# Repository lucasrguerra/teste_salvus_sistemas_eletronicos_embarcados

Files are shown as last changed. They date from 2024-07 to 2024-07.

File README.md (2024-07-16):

# Teste Técnico para a vaga de Desenvolvedor de Sistemas Eletrônicos Embarcados na Salvus

## Descrição

Este repositório contém minhas respostas para o teste técnico para a vaga de Desenvolvedor de Sistemas Eletrônicos Embarcados na Salvus.

O arquivo [Teste Técnico](Teste_Técnico-Lucas_Rayan_Guerra_da_Silva.pdf) contém a descrição e as questões do teste técnico, assim como as minhas respostas para as questões 2, 3, 4 e 5.

A pasta [Projeto](Projeto) contém os arquivos do projeto do circuito de fonte de alimentação regulada para um microcontrolador de baixa potência que opera com 3.3V a partir de uma fonte de 12V e/ou uma bateria.

A pasta [Arquivos_de_Fabricação](Arquivos_de_Fabricação) contém os arquivos de fabricação do circuito de fonte de alimentação regulada.

O arquivo [Lista_de_Materiais_(BOM)](Lista_de_Materiais_(BOM).csv) contém a lista de materiais (BOM) do circuito de fonte de alimentação regulada.

O arquivo [Esquemático](Esquemático.pdf) contém o esquemático do circuito de fonte de alimentação regulada.

Por questões de tempo, não foi possível realizar a simulação do circuito de fonte de alimentação regulada, devido a utilização de componentes específicos que não são encontrados um equivalente para simulação com facilidade, não tive disposnibilidade o suficiente para catalogar todos eles. Porém, por utilizar um esquema de ligação muito semelhante ao utilizado nos módulos prontos comercializados com o chip TP4056, acredito que o circuito proposto funcione corretamente, garantindo a alternância entre a fonte de alimentação e bateria, bem como as proteções contra sobrecarga e descarga excessiva da bateria.

## Justificativa do uso dos componentes

### Conectores KF301-2P

Eles foram escolhidos por ser de fácil conexão e desconexão, além de serem baratos e fáceis de encontrar.

### Capacitor C1

Ele foi escolhido para filtrar o ruído da fonte de alimentação e garantir que a tensão de entrada do regulador de tensão seja o mais estável possível.

### LED D1

Esse LED na cor verde foi escolhido para indicar que a fonte de alimentação está conectada e funcionando.

### LED D2

Esse LED na cor vermelha foi escolhido para indicar que a bateria está sendo carregada.

### Regulador LM7805

Ele foi escolhido para regular a tensão de entrada de 12V para 5V, que é a tensão utilizada para carregar a bateria. Vale ressaltar que o regulador LM7805 aceita tensões de 7V até 20V, então o circuito pode ser alimentado com tensões de 7V até 20V.

### Regulador AP2112-3.3

Ele foi escolhido para regular a tensão de 5V vinda da fonte de alimentação, ou a tensão da bateria, para 3.3V, que é a tensão de alimentação do microcontrolador. A característica mais importante para essa aplicação é que ele é um LDO (Low Drop-Out), ou seja, ele pode ser alimentado com tensões muito próximas da tensão de saída, o que é o caso quando a bateria está sendo utilizada.

### TP4056

Ele foi escolhido para controlar a carga da bateria de lítio. Ele é um módulo de carga de bateria de lítio de 1A. Ele é muito utilizado em projetos de carregadores de bateria de lítio, por ser barato e fácil de encontrar.

### DW01A

Ele foi escolhido para proteger a bateria de lítio contra sobrecarga e descarga excessiva. Ele normalmente é utilizado em conjunto com o TP4056.

### MOSFET FS8205A

Ele foi escolhido para alternar entre a fonte de alimentação e a bateria. Ele é um MOSFET de canal duplo, e também costuma ser utilizado em conjunto com o TP4056.

### Extras

Também foram acionados 2 barramentos de 2.54mm com 2 pinos cada para facilitar a conexão da bateria e do MCU via Jumpers.

## Images

A pasta [Imagens](Imagens) contém as imagens do circuito de fonte de alimentação regulada mostradas abaixo.

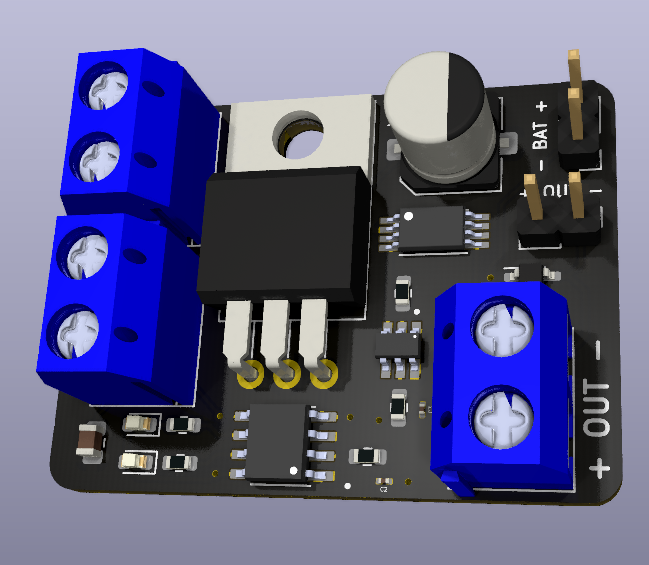
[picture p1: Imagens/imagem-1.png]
Imagem 1


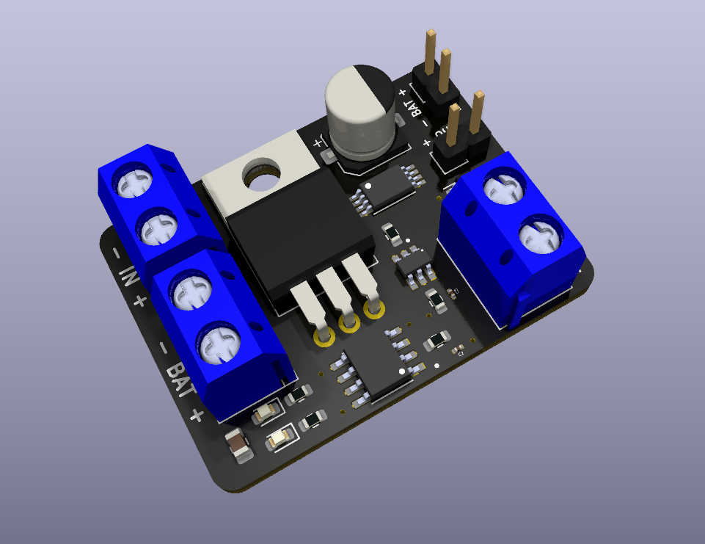
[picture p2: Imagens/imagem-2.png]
Imagem 2


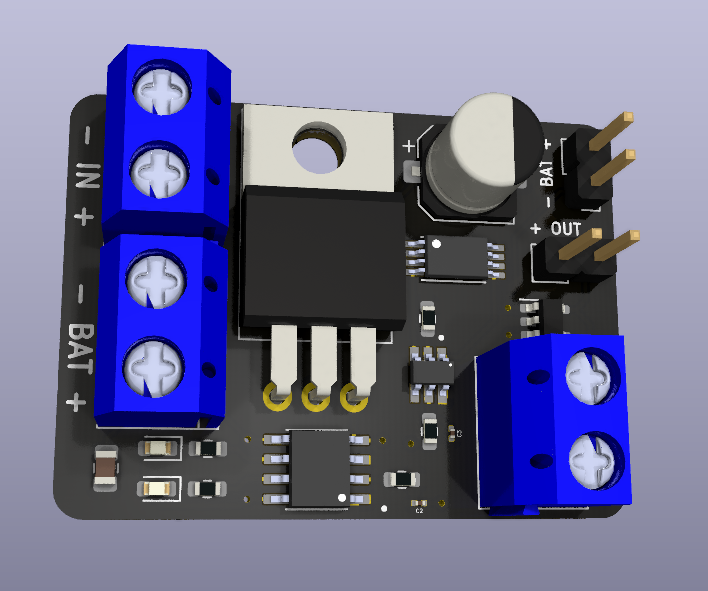
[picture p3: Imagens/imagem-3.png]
Imagem 3


Autor: Lucas Rayan Guerra da Silva

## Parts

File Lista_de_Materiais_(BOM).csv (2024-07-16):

Id | Designador | Footprint | Quantidade | Designação | Referência
1 | D1 | LED_0603_1608Metric | 1 | Green | LED Green 0603
2 | R2,R1,R4 | R_0603_1608Metric | 3 | 1kΩ | Resistor 1kΩ 0.1W 1% 0603
3 | J4,J5 | PinHeader_1x02_P2.54mm_Vertical | 2 | Conn_01x02 | Pin Header 1x02 2.54mm Vertical
4 | C4 | C_0805_2012Metric | 1 | 10uF 10V | Capacitor 10uF 10V 2012
5 | J3,J1,J2 | TerminalBlock_bornier-2_P5.08mm | 3 | KF301-2P | KF301-2P
6 | U1 | TO-220-3_Horizontal_TabDown | 1 | LM7805_TO220 | LM7805_TO220
7 | C3,C2 | C_0201_0603Metric | 2 | 100nF 6.3V | Capacitor 100nF 6.3V 0603
8 | U4 | SOT-23-5 | 1 | AP2112K-3.3 | AP2112K-3.3
9 | U2 | SOP127P600X175-9N | 1 | TP4056 | TP4056 SOP8
10 | R3 | R_0603_1608Metric | 1 | 1.2kΩ | Resistor 1.2kΩ 0.1W 1% 0603
11 | C1 | CP_Elec_6.3x7.7 | 1 | 100uF 35V | Electrolytic capacitor 100uF 35V 6.3x7.7
12 | Q1 | SOP65P640X120-8N | 1 | FS8205A | FS8205A SOP8
13 | D2 | LED_0603_1608Metric | 1 | Red | LED Red 0603
14 | R5 | R_0603_1608Metric | 1 | 100Ω | Resistor 100Ω 0.1W 1% 0603
15 | U3 | SOT95P280X145-6N | 1 | DW01A | DW01A SOT23

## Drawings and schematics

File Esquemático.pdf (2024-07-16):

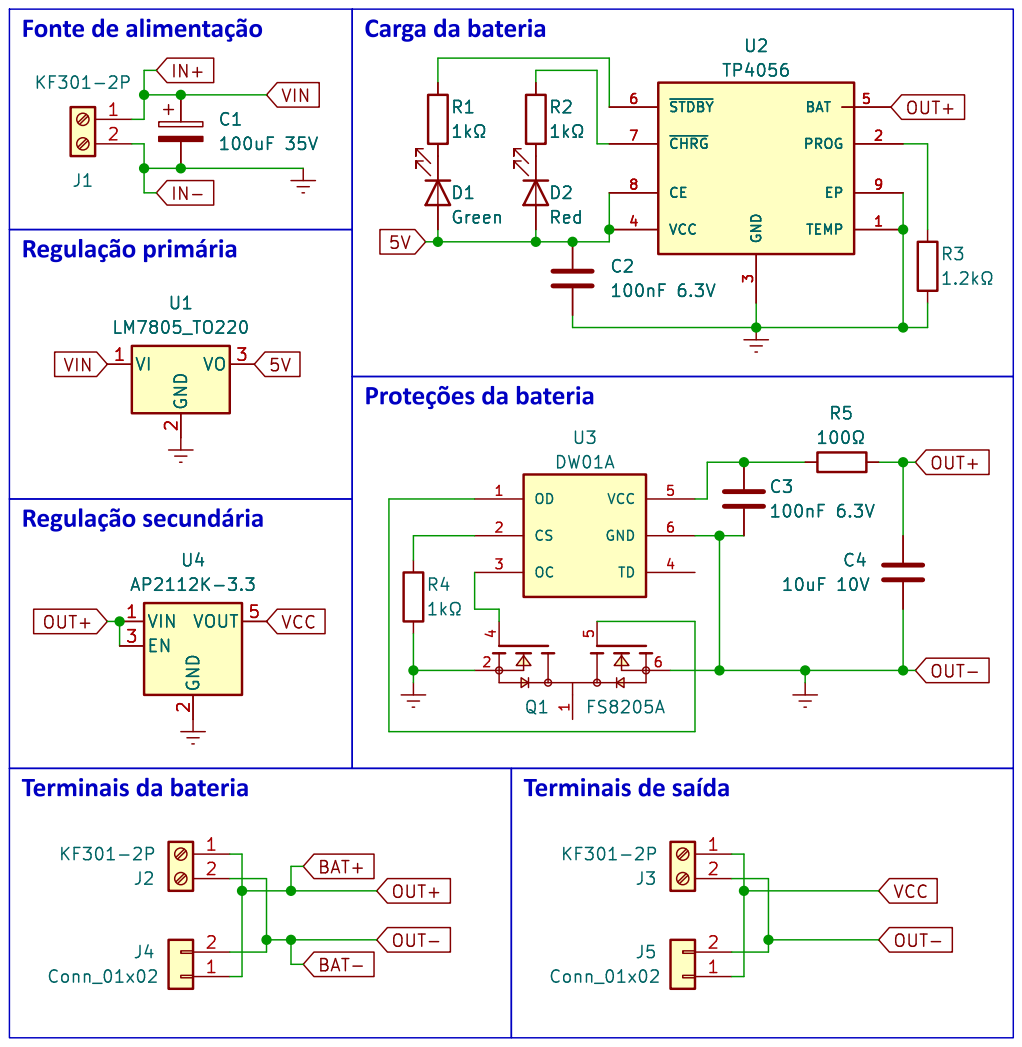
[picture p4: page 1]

3 VCC 4 BAT 5 ~{STDBY} 6 ~{CHRG} 7 CE 8 EP 9 U2 TP4056 R3

3 VCC 4 BAT 5 ~{STDBY} 6 ~{CHRG} 7 CE 8 EP 9 D2 Red R2
10uF 10V D2 Red R2

Id: 1/1 Title: þÿEsquemático do Teste þÿPrático

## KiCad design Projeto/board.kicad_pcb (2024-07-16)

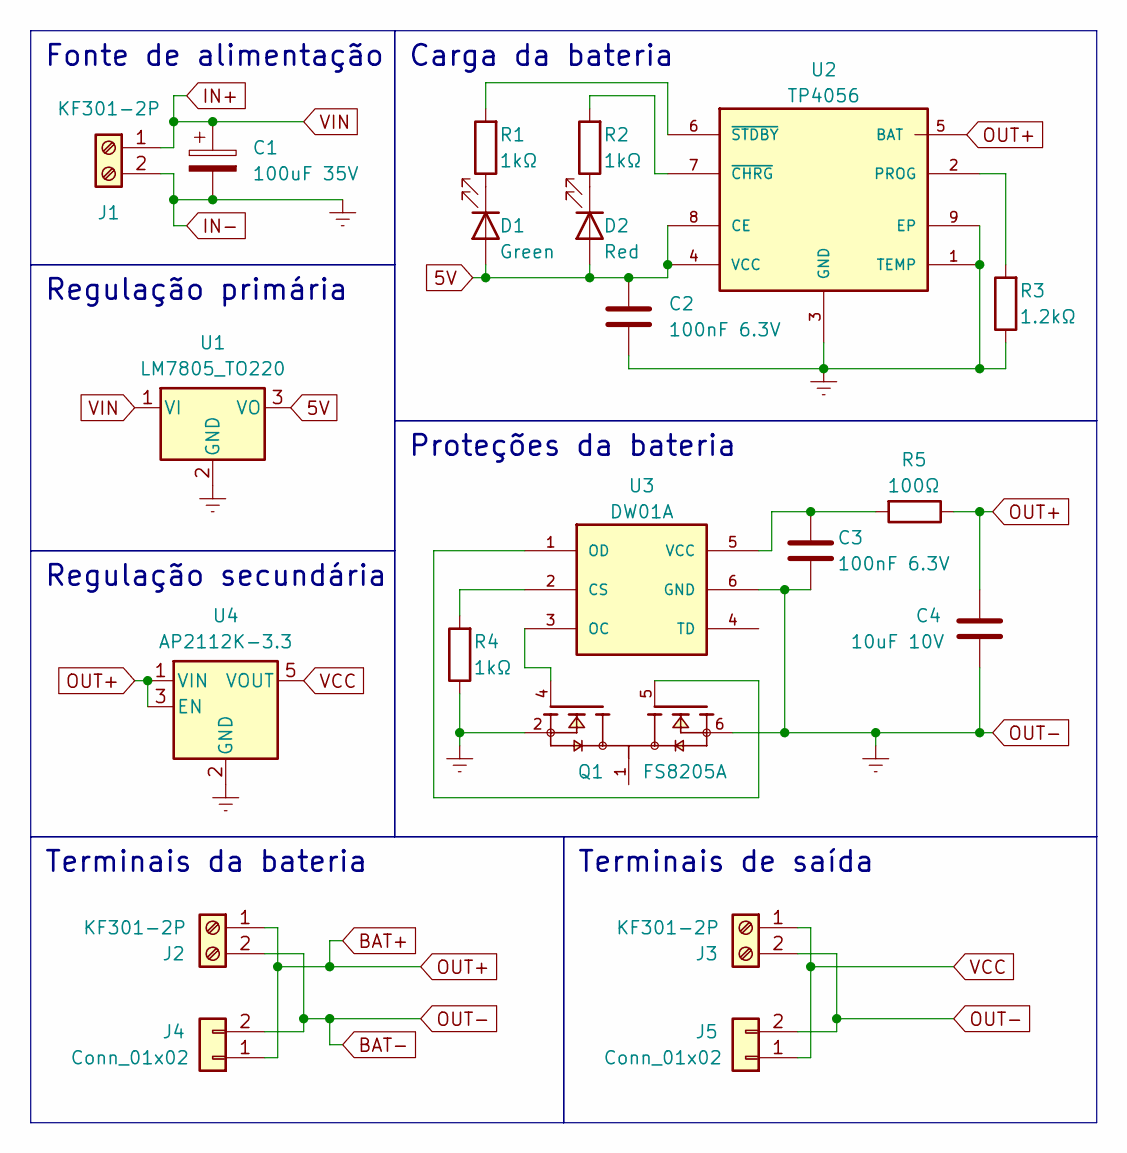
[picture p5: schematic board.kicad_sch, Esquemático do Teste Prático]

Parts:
C1: 100uF 35V; CP_Elec_6.3x7.7
C2, C3: 100nF 6.3V; C_0201_0603Metric
C4: 10uF 10V; C_0805_2012Metric
D1: Green; LED_0603_1608Metric
D2: Red; LED_0603_1608Metric
J1, J2, J3: KF301-2P; TerminalBlock_bornier-2_P5.08mm
J4, J5: Conn_01x02; PinHeader_1x02_P2.54mm_Vertical
Q1: FS8205A; SOP65P640X120-8N; PARTREV 1.7
R1, R2, R4: 1kΩ; R_0603_1608Metric
R3: 1.2kΩ; R_0603_1608Metric
R5: 100Ω; R_0603_1608Metric
U1: LM7805_TO220; TO-220-3_Horizontal_TabDown
U2: TP4056; SOP127P600X175-9N
U3: DW01A; SOT95P280X145-6N; PARTREV 1.8
U4: AP2112K-3.3; SOT-23-5

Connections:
5V: C2.1, D1.2 (A), D2.2 (A), U1.3 (VO), U2.4 (VCC), U2.8 (CE)
BAT+: C4.1, J2.1, J4.1, R5.1, U2.5 (BAT), U4.1 (VIN), U4.3 (EN)
BAT-: C1.2, C2.2, C3.2, C4.2, J1.2, J2.2, J3.2, J4.2, J5.2, Q1.2, Q1.6, R3.1, R4.1, U1.2 (GND), U2.1 (TEMP), U2.3 (GND), U2.9 (EP), U3.6 (GND), U4.2 (GND)
IN+: C1.1, J1.1, U1.1 (VI)
unnamed: D1.1 (K), R1.1
unnamed: D2.1 (K), R2.1
unnamed: R3.2, U2.2 (PROG)
unnamed: R2.2, U2.7 (~CHRG)
unnamed: R1.2, U2.6 (~STDBY)
unnamed: R4.2, U3.2 (CS)
unnamed: Q1.4, U3.3 (OC)
unnamed: Q1.5, U3.1 (OD)
unnamed: C3.1, R5.2, U3.5 (VCC)
VCC: J3.1, J5.1, U4.5 (VOUT)

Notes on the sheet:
Regulação primária
Proteções da bateria
Carga da bateria
Fonte de alimentação
Terminais da bateria
Regulação secundária
Terminais de saída

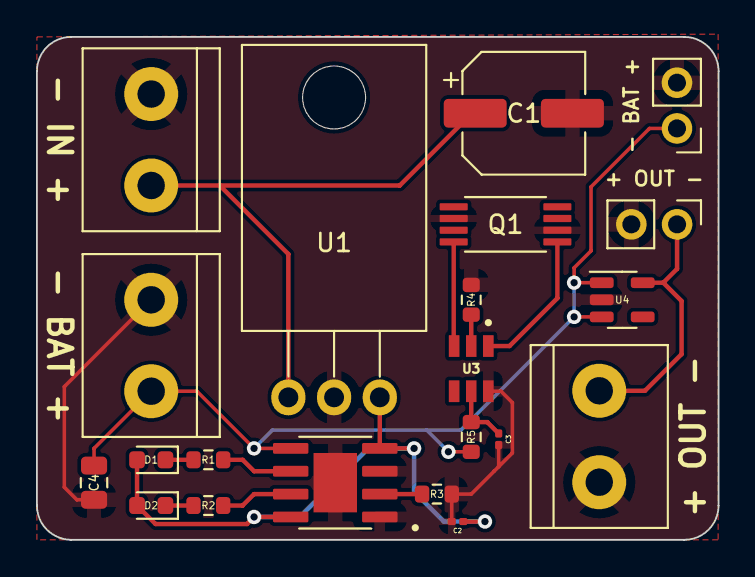
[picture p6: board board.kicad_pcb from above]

Board: 2 copper layers, 37.9 x 27.9 mm, 21 parts (0 on the bottom side), 14 nets.
